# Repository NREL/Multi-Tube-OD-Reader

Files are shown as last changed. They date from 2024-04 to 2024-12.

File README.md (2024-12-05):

# Multi-Tube-OD-Reader
### Author: Skyler Hebdon, PhD
### Overview
Our **Multi-Tube-OD-Reader** device is based on the TubeOD reader [published here](https://doi.org/10.3389/fmicb.2021.790576), but with a housing to maximize throughput.

This repository contains the schematics for 3D printing an enclosure, a parts list for constructing, and the code for controlling the 16-tube, in-line optical density monitoring device. This device and software are particularly useful for researchers studying microbes that grow well in Hungate tubes, but are not amenable to growth in microplate readers.

- [Features](#features)
- [Limitations](#limitations)
- [Tutorial](#interacting-with-the-instrument)
- [Installation](#installation)
- [For Developers](#app-structure-mostly-for-developers--troubleshooting)
- [License](#license)

### Features
- **Real-time Monitoring:** View the OD measurements of multiple cultures in real time. Supports multiple, simultaneous, independent experiments.
- **User-Friendly Interface:** Easy-to-use, browser-based GUI for data collection and managing hardware. Install the software, connect the USB cable, connect the power cable and it's ready to go.
- **Calibration-ready:** Supports custom calibration tables to scale optical density readings to your favorite standard instrument. Raw data are always saved. Interpreted data can be saved as an xlsx file and include calibration tables. 
- **Multi-User Safe:** Experiments are spun-off as independent processes that continue even if the app is closed. Unique file naming is enforced to ensure that previous data cannot be overwritten. 
- **High throughput:** Connect as many Multi-Tube-OD-Readers as your incubator can hold. USB splitters and GUI allow identification and control of parallel independent instruments.

[Back to top](#overview)
### Limitations
- The hardware was designed for observing optical densities of *Clostridium thermocellum* growing in glass Hungate tubes. The optical properties of the glassware, medium and organism can interfere with the sensitivity of the instrument, especially at lower optical densities.
- The code works for us. It is not extensively tested and may require some modification on your machine.

[Back to top](#overview)
### Interacting with the Instrument
#### Nomenclature
- A *Device* is the whole unit with 16 Ports in it.
- A *Port* holds and measures one tube. Each Port can operate independently.
- An *Experiment* is a set of Ports & Devices taking measurements. Experiments run in the background indefinitely, until they are shut off in the app by the user or until the computer restarts.
#### Instrument Setup
Initial installation instructions are provided below. For routine use...

**Start the Shiny App** (if necessary) 
```
#from the Multi-Tube-OD-Reader directory
python -m shiny run --reload --launch-browser my_app/app.py 
```
This should open your default web browser and show the user interface.
### User Interface
#### Home: 
- View & interact with ongoing Experiments.
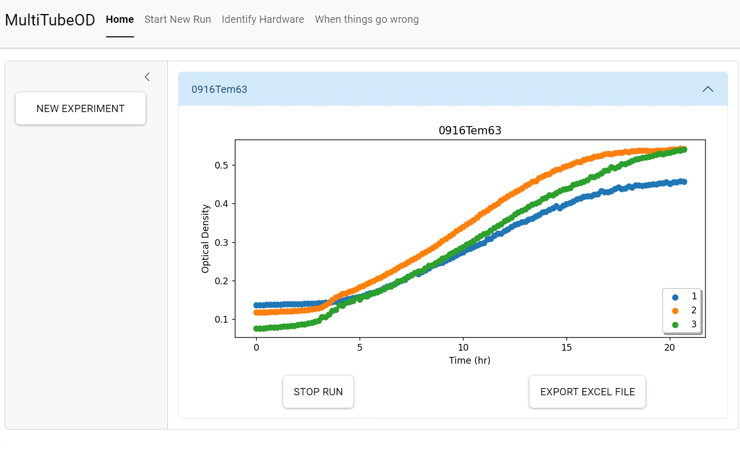
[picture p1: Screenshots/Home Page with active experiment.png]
Image of Home Page with growth curve data showing for an active experiment


- Safeguards protect from accidentally stopping the run.
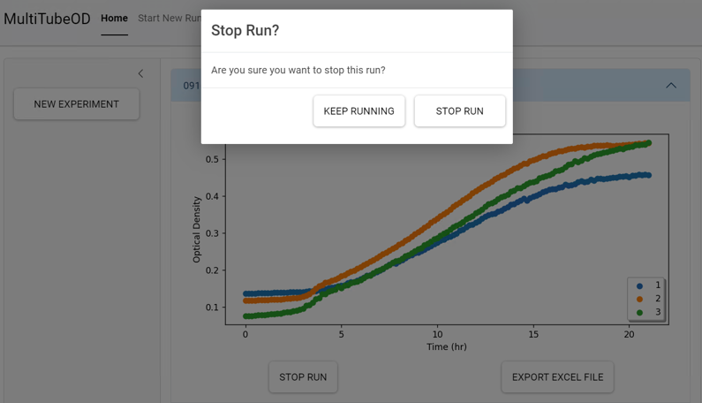
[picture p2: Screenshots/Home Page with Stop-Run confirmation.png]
Image of Home Page with a popup confirming user's intention to shut down the run


#### Start New Run:
- Step 1: Experiment name and measurement interval
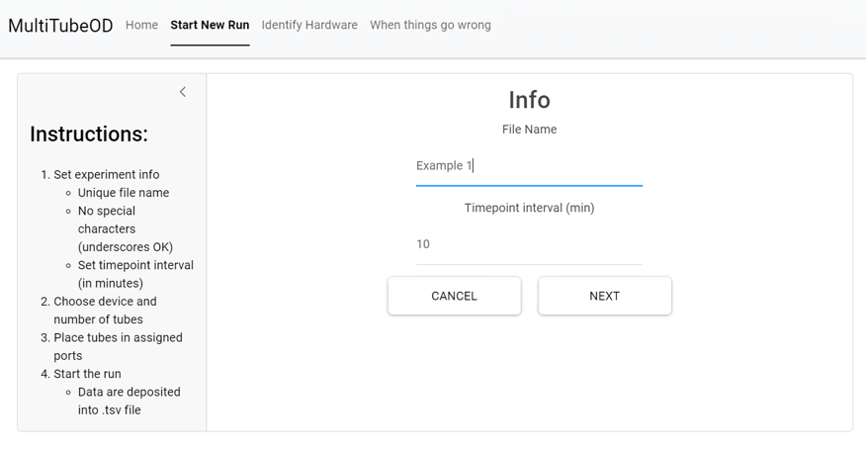
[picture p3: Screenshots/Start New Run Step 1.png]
Image of Start New Run page accepting experiment name and time interval inputs


- Safeguards to protect from overwriting previous data files.
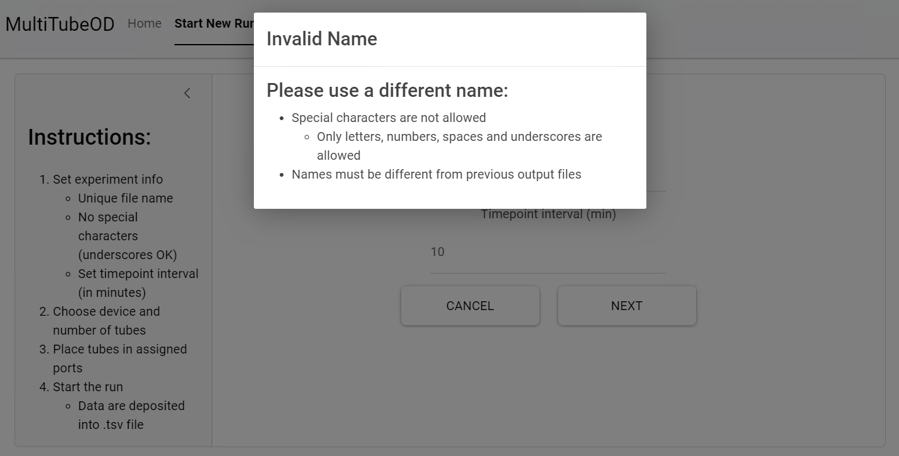
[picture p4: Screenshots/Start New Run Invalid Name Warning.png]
Image of Start New Run page warning user that the file name already exists


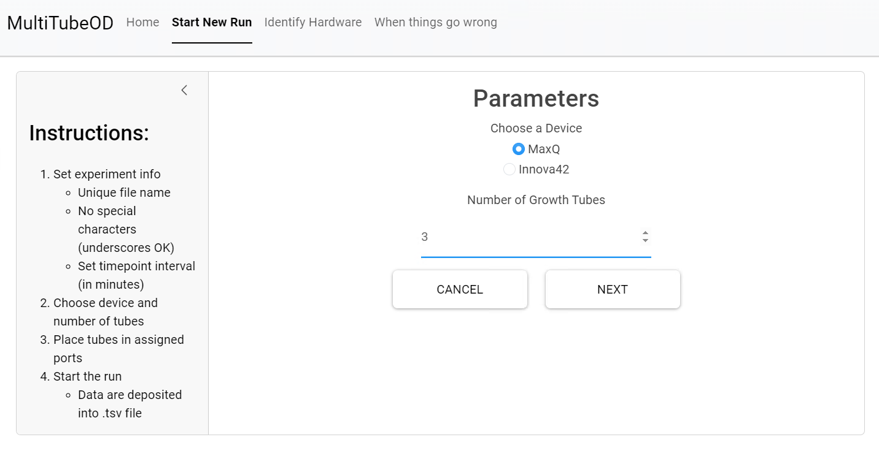
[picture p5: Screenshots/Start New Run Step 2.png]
Image of Start New Run page showing options for attached devices and number of available ports
- Step 2: Select device and number of Ports. We named our devices based on the incubators they live in. 

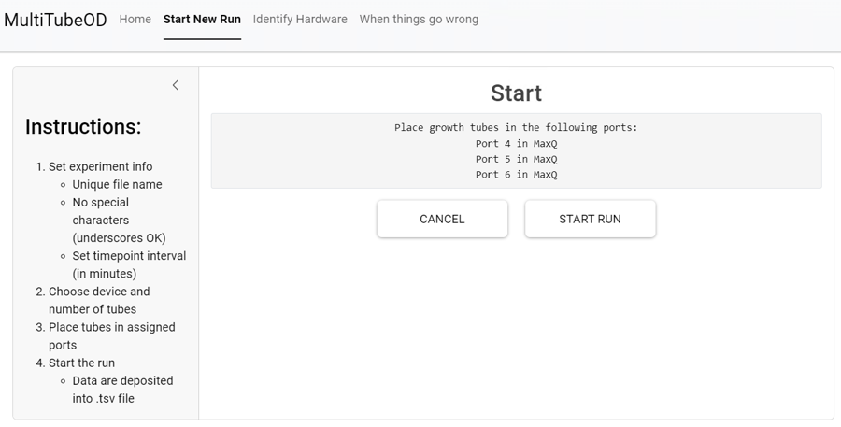
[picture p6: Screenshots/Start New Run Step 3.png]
Image of Start New Run page showing instructions on where to place culture tubes
- Step 3: Place growth tubes. Ports are automatically assigned based on availability. 

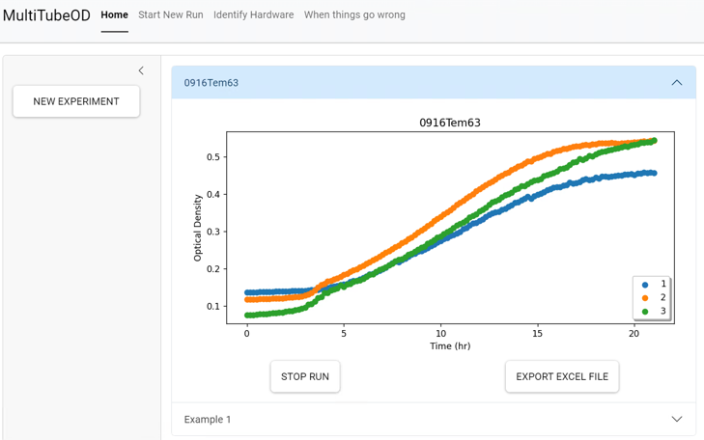
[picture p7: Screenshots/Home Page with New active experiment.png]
Image of Home Page with a new experiment added
- Complete: The User is automatically redirected to the Home Page with the New Experiment added to the list of Active Experiments. 

#### Configure Hardware:
- Identify and Rename devices. The Blink button makes the indicator LED blink on the device. 
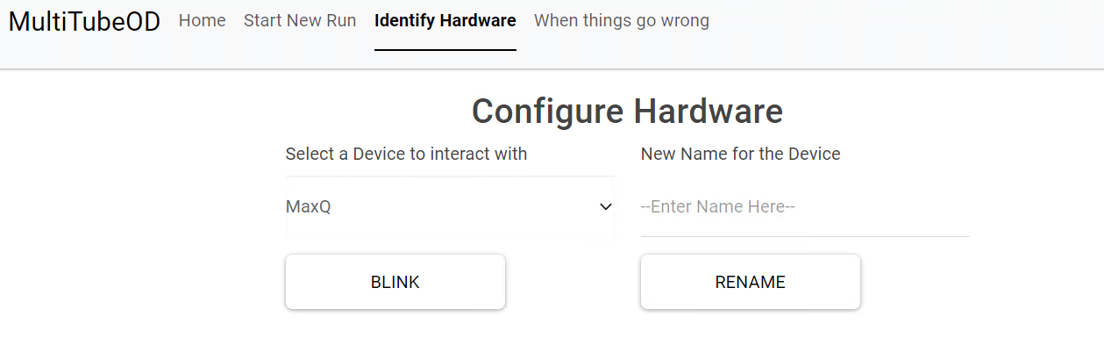
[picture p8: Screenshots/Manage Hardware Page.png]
Image of Configure Hardware page showing options to select a device, make it blink and rename it


#### Calibration: 
Performed mostly offline, no tab for this function
- Prepare reference tubes to several known optical densities. 
- Measure each reference level using each port the Multi-Tube-OD-Reader
- Transform raw Voltage data to log<sub>10</sub>( Voltage ) 
- Fit a line with y = Known data and x = log<sub>10</sub>( Voltage )
- Update the slope & intercept for each port and other relevant data into the `Calibration.tsv` found in the `my_app` directory.

[Back to top](#overview)
### Installation 
#### Hardware
The hardware requires two connections:
1. A USB cable for data transfer to the computer.
	- USB splitters can be used to branch one USB cable from the computer to multiple Devices. This can help reduce the number of cables passing through the incubator.
2. A power supply cable providing up to about 0.5 amps of 5V DC electrical power.
#### Software
The app requires a Python environment and a U3-compatible driver from [LabJack.com](https://support.labjack.com/docs/labjackpython-for-ud-exodriver-u12-windows-mac-lin).
- For Windows: the UD Driver
- Linux macOS: the Exodriver 

All other required packages are either listed in the `requirements.txt` file or provided in this repository. The following instructions are a typical way to install all of them.

**Copy this Repository to the Computer connected to the Device:** 
 ```
 git clone https://github.com/NREL/Multi-Tube-OD-Reader.git
 ```

**Navigate to the Project Directory:**
```
cd Multi-Tube-OD-Reader
```

**Create a Virtual Environment (Optional):**
Windows users may have different strategies for activating a python virtual environment in WSL vs cmd vs PowerShell. PowerShell users see [this answer](https://stackoverflow.com/a/59815372) 
```
python -m venv MTOD
source MTOD/bin/activate 
```

**Install Dependencies:**
```
pip install -r my_app/requirements.txt
```

**Start the Shiny App**
```
#from Multi-Tube-OD-Reader directory
python -m shiny run --reload --launch-browser my_app/app.py 
```

[Back to top](#overview)
### App Structure (mostly for developers & troubleshooting)
The app was written in Python using modules in a three-tier architecture:
1. *A minimal* `timecourse.py` *script*. This script, and the receives a `.csv` file with instructions in the header that describe the measurement parameters. This script controls the Multi-Tube-OD-Reader device throughout the duration of an experiment and feeds raw data into the `.csv` file. This script was designed to be lightweight so multiple parallel-independent instances can run simultaneously without crashing the computer.
2. *Three custom Python classes* `Device`, `Port`, *and* `Experiment` *mirroring their physical counterparts.* Objects of these classes convey data between the GUI, a `config.dat` file, and the instrument. The `config.dat` file stores the status of the instrument and active experiments in case the app closes. Only the `Device` class (and `timecourse.py` script) interact directly with the instrument.
3. *Modules comprising the GUI. Written in Shiny for Python.* This runs a server on localhost. Advanced users may be able to serve the app to remote clients to monitor the data. We simply use remote login to the laptop running the app. The modules on this tier serve several functions:
	1. Convert user parameters to inputs to `timecourse.py` 
	2. Store instrument and app state in `config.dat`
	3. Calculate valid options for user input
	4. Reject or correct invalid user input

[Back to top](#overview)
### License
The hardware and software were built from open source resources. The material in this repository were developed at the National Renewable Energy Laboratory, with the code being reported under SWR-24-126. The materials in this repository are subject to the BSD-3-Clause License. 

**No Guarantees:**
- **Accuracy:** We make no representations or warranties about the accuracy, reliability, completeness, or timeliness of the content. The instructions and information provided may contain errors or inaccuracies.
- **Functionality:** We do not guarantee that the hardware or software will function correctly or meet your needs. There may be unforeseen issues or incompatibilities that arise during implementation.
- **Support:** There is no obligation to provide support, maintenance, or updates for the materials provided in this repository.

[Back to top](#overview)

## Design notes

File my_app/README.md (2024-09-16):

# Multi-Tube-OD-Reader
### Overview
Our **Multi-Tube-OD-Reader** device is based on the TubeOD reader [published here](https://doi.org/10.3389/fmicb.2021.790576), but with a housing to maximize throughput.

This repository contains the schematics for 3D printing an enclosure, a parts list for constructing, and the code for controlling the 16-tube, in-line optical density monitoring device. This device and software are particularly useful for researchers studying microbes that grow well in Hungate tubes, but are not amenable to growth in microplate readers.
### Features
- **Real-time Monitoring:** View the OD measurements of multiple cultures in real time. Supports multiple, simultaneous, independent experiments.
- **User-Friendly Interface:** Easy-to-use, browser-based GUI for data collection and managing hardware. Install the software, connect the USB cable, connect the power cable and it's ready to go.
- **Calibration-ready:** Supports custom calibration tables to scale optical density readings to your favorite standard instrument. Raw data are always saved. Interpreted data can be saved as an xlsx file and include calibration tables. 
- **Multi-User Safe:** Experiments are spun-off as independent processes that continue even if the app is closed. Unique file naming is enforced to ensure that previous data cannot be overwritten. 
- **High throughput:** Connect as many Multi-Tube-OD-Readers as your incubator can hold. USB splitters and GUI allow identification and control of parallel independent instruments.
### Limitations
- The hardware was designed for observing optical densities of *Clostridium thermocellum* growing in glass Hungate tubes. The optical properties of the glassware, medium and organism can interfere with the sensitivity of the instrument, especially at lower optical densities.
- The code works for us. It is not extensively tested and may require some modification on your machine.
### Interacting with the Instrument and GUI
##### Nomenclature
- A *Device* is the whole unit with 16 Ports in it.
- A *Port* holds and measures one tube. Each Port can operate independently.
- An *Experiment* is a set of Ports & Devices taking measurements. Experiments run in the background indefinitely, until they are shut off in the app by the user or until the computer restarts.
##### Instrument Setup
Initial installation instructions are provided below. For routine use...
**Start the Shiny App** (if necessary) 
```
#from the Multi-Tube-OD-Reader directory
python -m shiny run --reload --launch-browser my_app/app.py 
```
This should open your default web browser and show the user interface.
##### User Interface
**Home:** View ongoing Experiments.
- Minimize or expand experiments to view data and reveal options to export interpreted data or terminate the experiment. 
**Start New Run:** Define the following parameters for starting a new Experiment.
- Experiment Name
- Interval between measurements 
- Name of Device to use
- Number of Ports to use
**Configure Hardware:** Manage connected devices.
- Select Device by name
- Activate LED "Blink" mode on hardware
- Rename Device with a meaningful identifier

**Calibration** (performed mostly offline, no tab for this function)
- Prepare reference tubes to several known optical densities. 
- Measure each reference level using each port the Multi-Tube-OD-Reader
- Transform raw Voltage data to log$_{10}$( Voltage ) 
- Fit a line with y = Known data and x = log$_{10}$( Voltage )
- Update the slope & intercept for each port and other relevant data into the `Calibration.tsv` found in the `my_app` directory.
### Installation 
##### Hardware
The hardware requires two connections:
1. A USB cable for data transfer to the computer.
	- USB splitters can be used to branch one USB cable from the computer to multiple Devices. This can help reduce the number of cables passing through the incubator.
2. A power supply cable providing up to about 0.5 amps of 5V DC electrical power.
##### Software
The app requires a U3-compatible driver from [LabJack.com](https://support.labjack.com/docs/labjackpython-for-ud-exodriver-u12-windows-mac-lin).
- For Windows: the UD Driver
- Linux macOS: the Exodriver 

All other required packages are either listed in the `requirements.txt` file or provided in this repository. The following instructions are a typical way to install all of them.

**Copy this Repository to the Computer connected to the Device:** 
 ```
 git clone https://github.com/NREL/Multi-Tube-OD-Reader.git
 ```

**Navigate to the Project Directory:**
```
cd Multi-Tube-OD-Reader
```

**Create a Virtual Environment (Optional):**
Windows users may have different strategies for activating a python virtual environment in WSL vs cmd vs PowerShell. PowerShell users see [this answer](https://stackoverflow.com/a/59815372) 
```
python -m venv MTOD
source MTOD/bin/activate 
```

**Install Dependencies:**
```
pip install -r my_app/requirements.txt
```

**Start the Shiny App**
```
#from Multi-Tube-OD-Reader directory
python -m shiny run --reload --launch-browser my_app/app.py 
```
### App Structure (mostly for developers & troubleshooting)

The app was written in Python using modules in a three-tier architecture:
1. *A minimal* `timecourse.py` *script*. This script, and the receives a `.csv` file with instructions in the header that describe the measurement parameters. This script controls the Multi-Tube-OD-Reader device throughout the duration of an experiment and feeds raw data into the `.csv` file. This script was designed to be lightweight so multiple parallel-independent instances can run simultaneously without crashing the computer.
2. *Three custom Python classes* `Device`, `Port`, *and* `Experiment` *mirroring their physical counterparts.* Objects of these classes convey data between the GUI, a `config.dat` file, and the instrument. The `config.dat` file stores the status of the instrument and active experiments in case the app closes. Only the `Device` class (and `timecourse.py` script) interact directly with the instrument.
3. *Modules comprising the GUI. Written in Shiny for Python.* This runs a server on localhost. Advanced users may be able to serve the app to remote clients to monitor the data. We simply use remote login to the laptop running the app. The modules on this tier serve several functions:
	1. Convert user parameters to inputs to `timecourse.py` 
	2. Store instrument and app state in `config.dat`
	3. Calculate valid options for user input
	4. Reject or correct invalid user input
### License
The hardware and software were built from open source resources. The material in this repository were developed at the National Renewable Energy Laboratory under the Laboratory-Directed Research & Development program. The materials in this repository are subject to  ##########License##############

**No Guarantees:**
- **Accuracy:** We make no representations or warranties about the accuracy, reliability, completeness, or timeliness of the content. The instructions and information provided may contain errors or inaccuracies.
- **Functionality:** We do not guarantee that the hardware or software will function correctly or meet your needs. There may be unforeseen issues or incompatibilities that arise during implementation.
- **Support:** There is no obligation to provide support, maintenance, or updates for the materials provided in this repository.

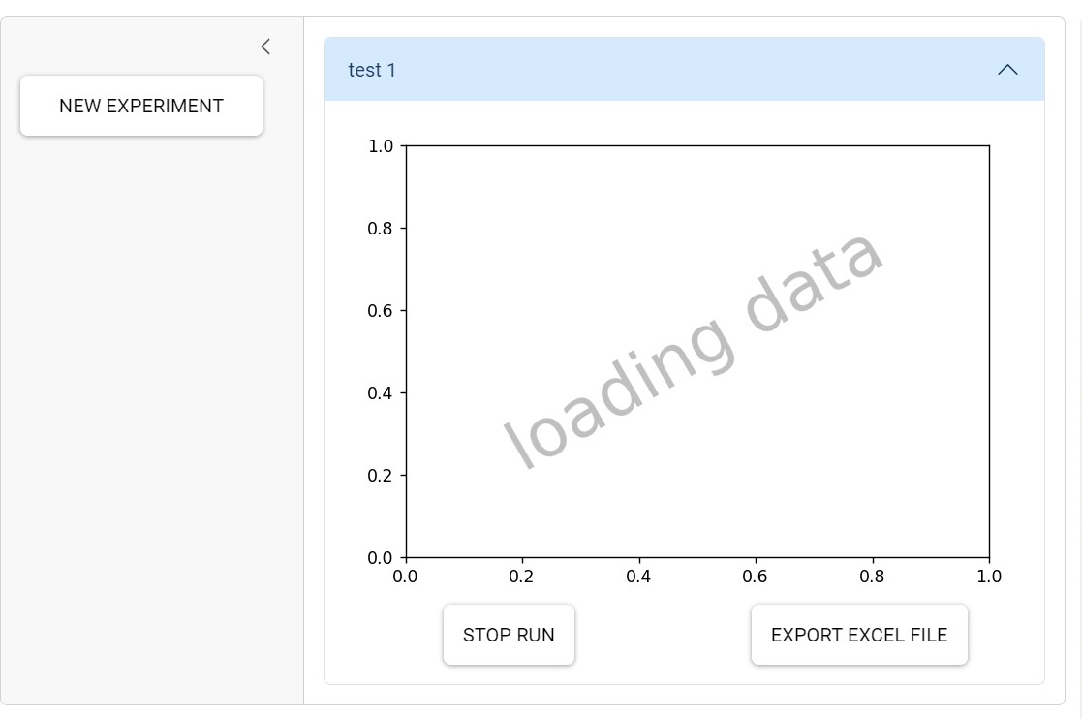
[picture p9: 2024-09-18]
Screenshots/Data loading screen.jpg

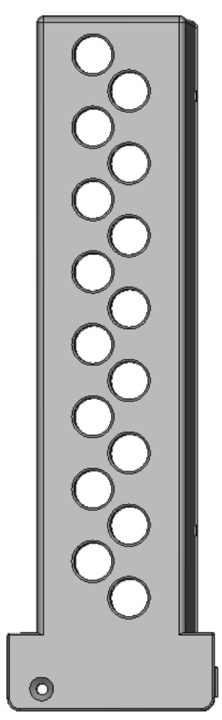
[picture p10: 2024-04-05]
my_app/cover.png

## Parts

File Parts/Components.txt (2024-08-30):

Part	Supplier	MFR #	Supplier #	Per tube	per unit
LED	Digikey		C566C-AFF-CU0W0252CT-ND	1	16
LED Driver IC	Digikey		CL220N5-G-ND	1	16
sensor	Amazon	TEMT6000	https://www.amazon.com/Coliao-TEMT6000-Professional-Intensity-Visible/dp/B0BZTZHRZS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	1	16
3-pin receptacle	Newark 	22-01-3037	38C9145	1	16
3-pin 90 degree header	Digikey		WM4301-ND	1	16
Contact sockets	Newark 	08-50-0032	62X0650	3	48
2-conductor cable - 22 gauge	Digikey	30-01253	T1412-5-ND		
3-conductor cable - 22 gauge	Digikey	8450 0101000	BEL1308-50-ND		
10-pin receptacle (locking)	Digikey	wm8037-nd	901420010		
10-pin header (locking)	Digikey	wm8325-nd	901301110		
Crimps for 10-pin header			WM2510-ND		
LabJack	LabJack				1
USB cable	Digikey		5214-USBAB2ML-ND		1
USB header	Newark 	USBR-B-S-S-O-TH	14R4574		1
2.1 mm x 5.5 mm Barrel jack to 18 gauge bare wire	Digikey	10-03610	839-10-03610-ND		1
"power supply, 2.5mm x 5.5mm x 9.5 mm"	Digikey	16-00015	839-1660-ND		1
LM317	Digikey		296-13869-5-ND		1
Solidstate relay	Digikey	AM37	3008-AB37-ND		1
screws (pack of 50)	Digikey		HM1442-ND		36
long screws (pack of 100)	Digikey	1591TS100			4

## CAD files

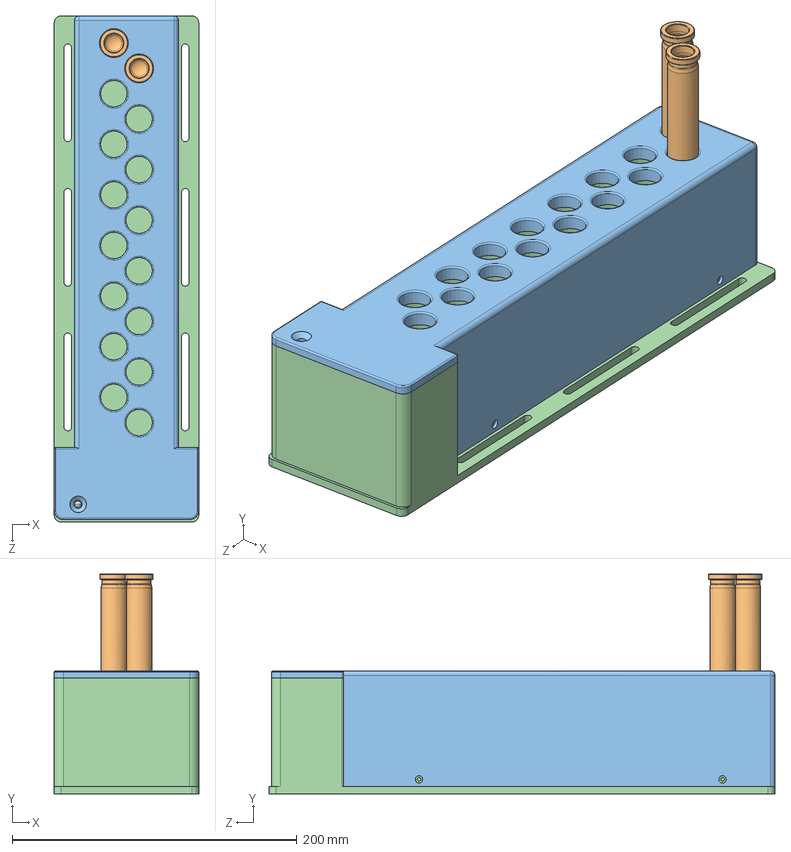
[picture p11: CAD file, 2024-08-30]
Parts/3181-03-00.SLDASM
101.6 x 154.4 x 355.6 mm
u3_pcba-20201207

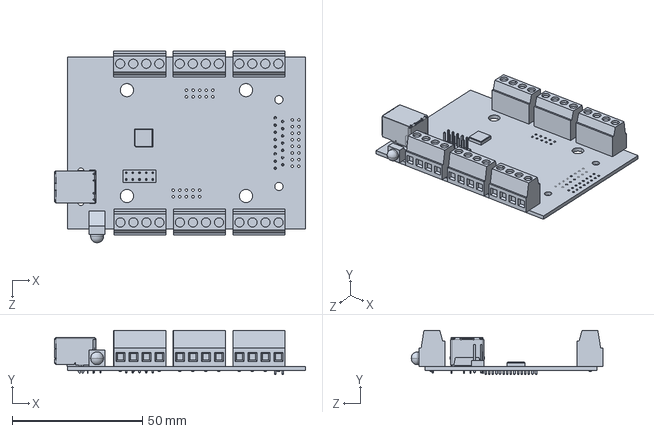
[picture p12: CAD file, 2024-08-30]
Parts/u3_pcba-20201207.SLDPRT
96.4 x 17.0 x 73.6 mm

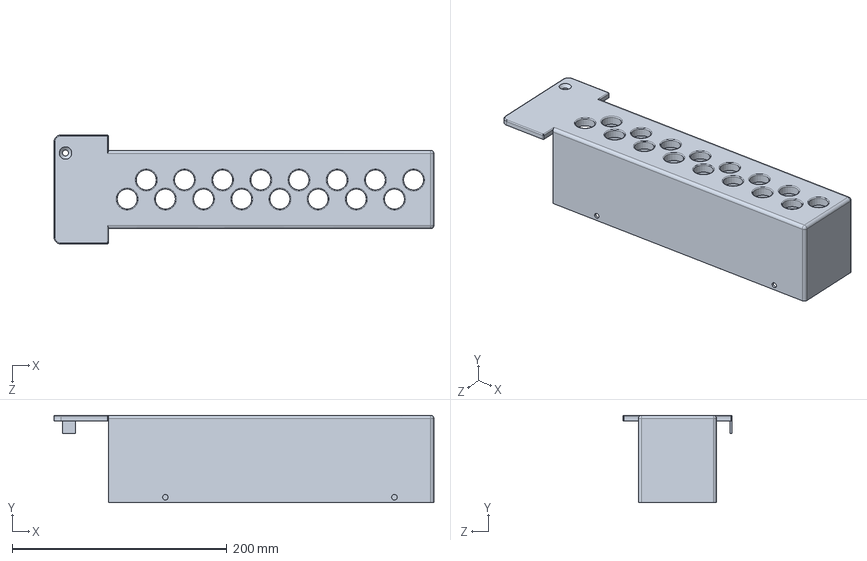
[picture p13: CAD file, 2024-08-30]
Parts/3181-03-01.SLDPRT
353.9 x 81.4 x 101.6 mm

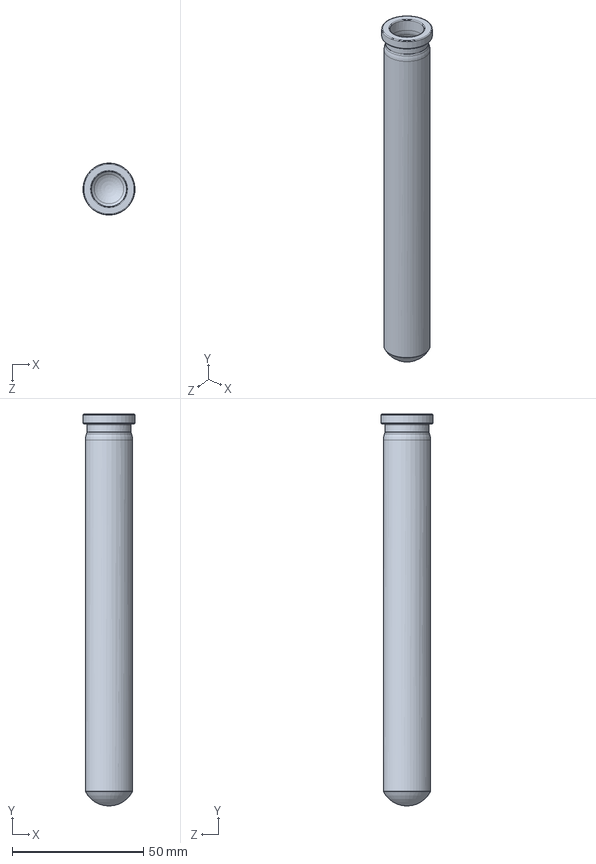
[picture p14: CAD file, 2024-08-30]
Parts/3181-00-01.SLDPRT
19.8 x 149.3 x 19.8 mm

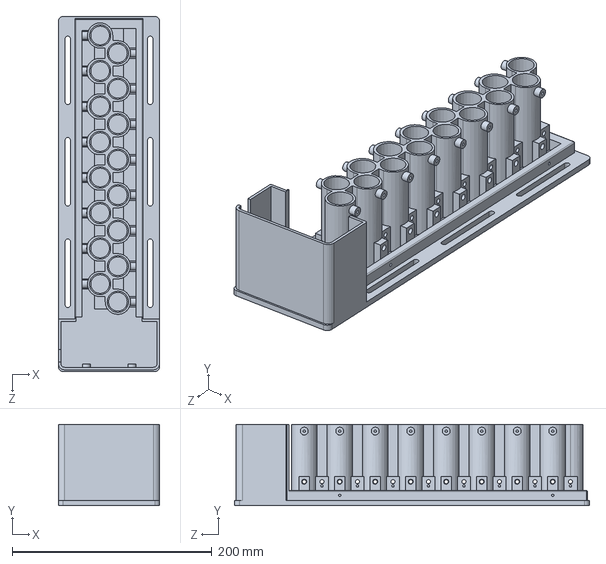
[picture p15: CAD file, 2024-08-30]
Parts/3181-03-02.SLDPRT
101.6 x 81.3 x 355.6 mm

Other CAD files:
Parts/3181-03-00.SLDDRW
Parts/3181-03-01.SLDDRW
Parts/3181-03-02.SLDDRW

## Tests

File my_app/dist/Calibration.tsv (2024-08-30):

DeviceID | Port | Slope | Intercept | R^2 | Date
320025052 | 1 | -0.49810642 | 0.287882165 | 0.997644899 | 7/29/2024
320025052 | 2 | -0.490788072 | 0.288915886 | 0.998286524 | 7/29/2024
320025052 | 3 | -0.490815332 | 0.337320501 | 0.998269742 | 7/29/2024
320025052 | 4 | -0.480658977 | 0.359227182 | 0.998849789 | 7/29/2024
320025052 | 5 | -0.489034053 | 0.31131613 | 0.998755798 | 7/29/2024
320025052 | 6 | -0.485325195 | 0.33445871 | 0.998549341 | 7/29/2024
320025052 | 7 | -0.492118058 | 0.327207934 | 0.998784087 | 7/29/2024
320025052 | 8 | -0.484903094 | 0.325601678 | 0.99828353 | 7/29/2024
320025052 | 9 | -0.495081668 | 0.301432224 | 0.998768022 | 7/29/2024
320025052 | 10 | -0.510185944 | 0.361506642 | 0.999956892 | 7/29/2024
320025052 | 11 | -0.498155733 | 0.303244371 | 0.998926699 | 7/29/2024
320025052 | 12 | -0.488435079 | 0.335390904 | 0.998651473 | 7/29/2024
320025052 | 13 | -0.485769313 | 0.350722889 | 0.998706716 | 7/29/2024
320025052 | 14 | -0.458743106 | 0.337553022 | 0.99877131 | 7/29/2024
320025052 | 15 | -0.489257424 | 0.353872979 | 0.99880573 | 7/29/2024
320025052 | 16 | -0.507890228 | 0.233422262 | 0.99757943 | 7/29/2024
320106158 | 1 | 1 | -0.001 | 1 | Fake
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

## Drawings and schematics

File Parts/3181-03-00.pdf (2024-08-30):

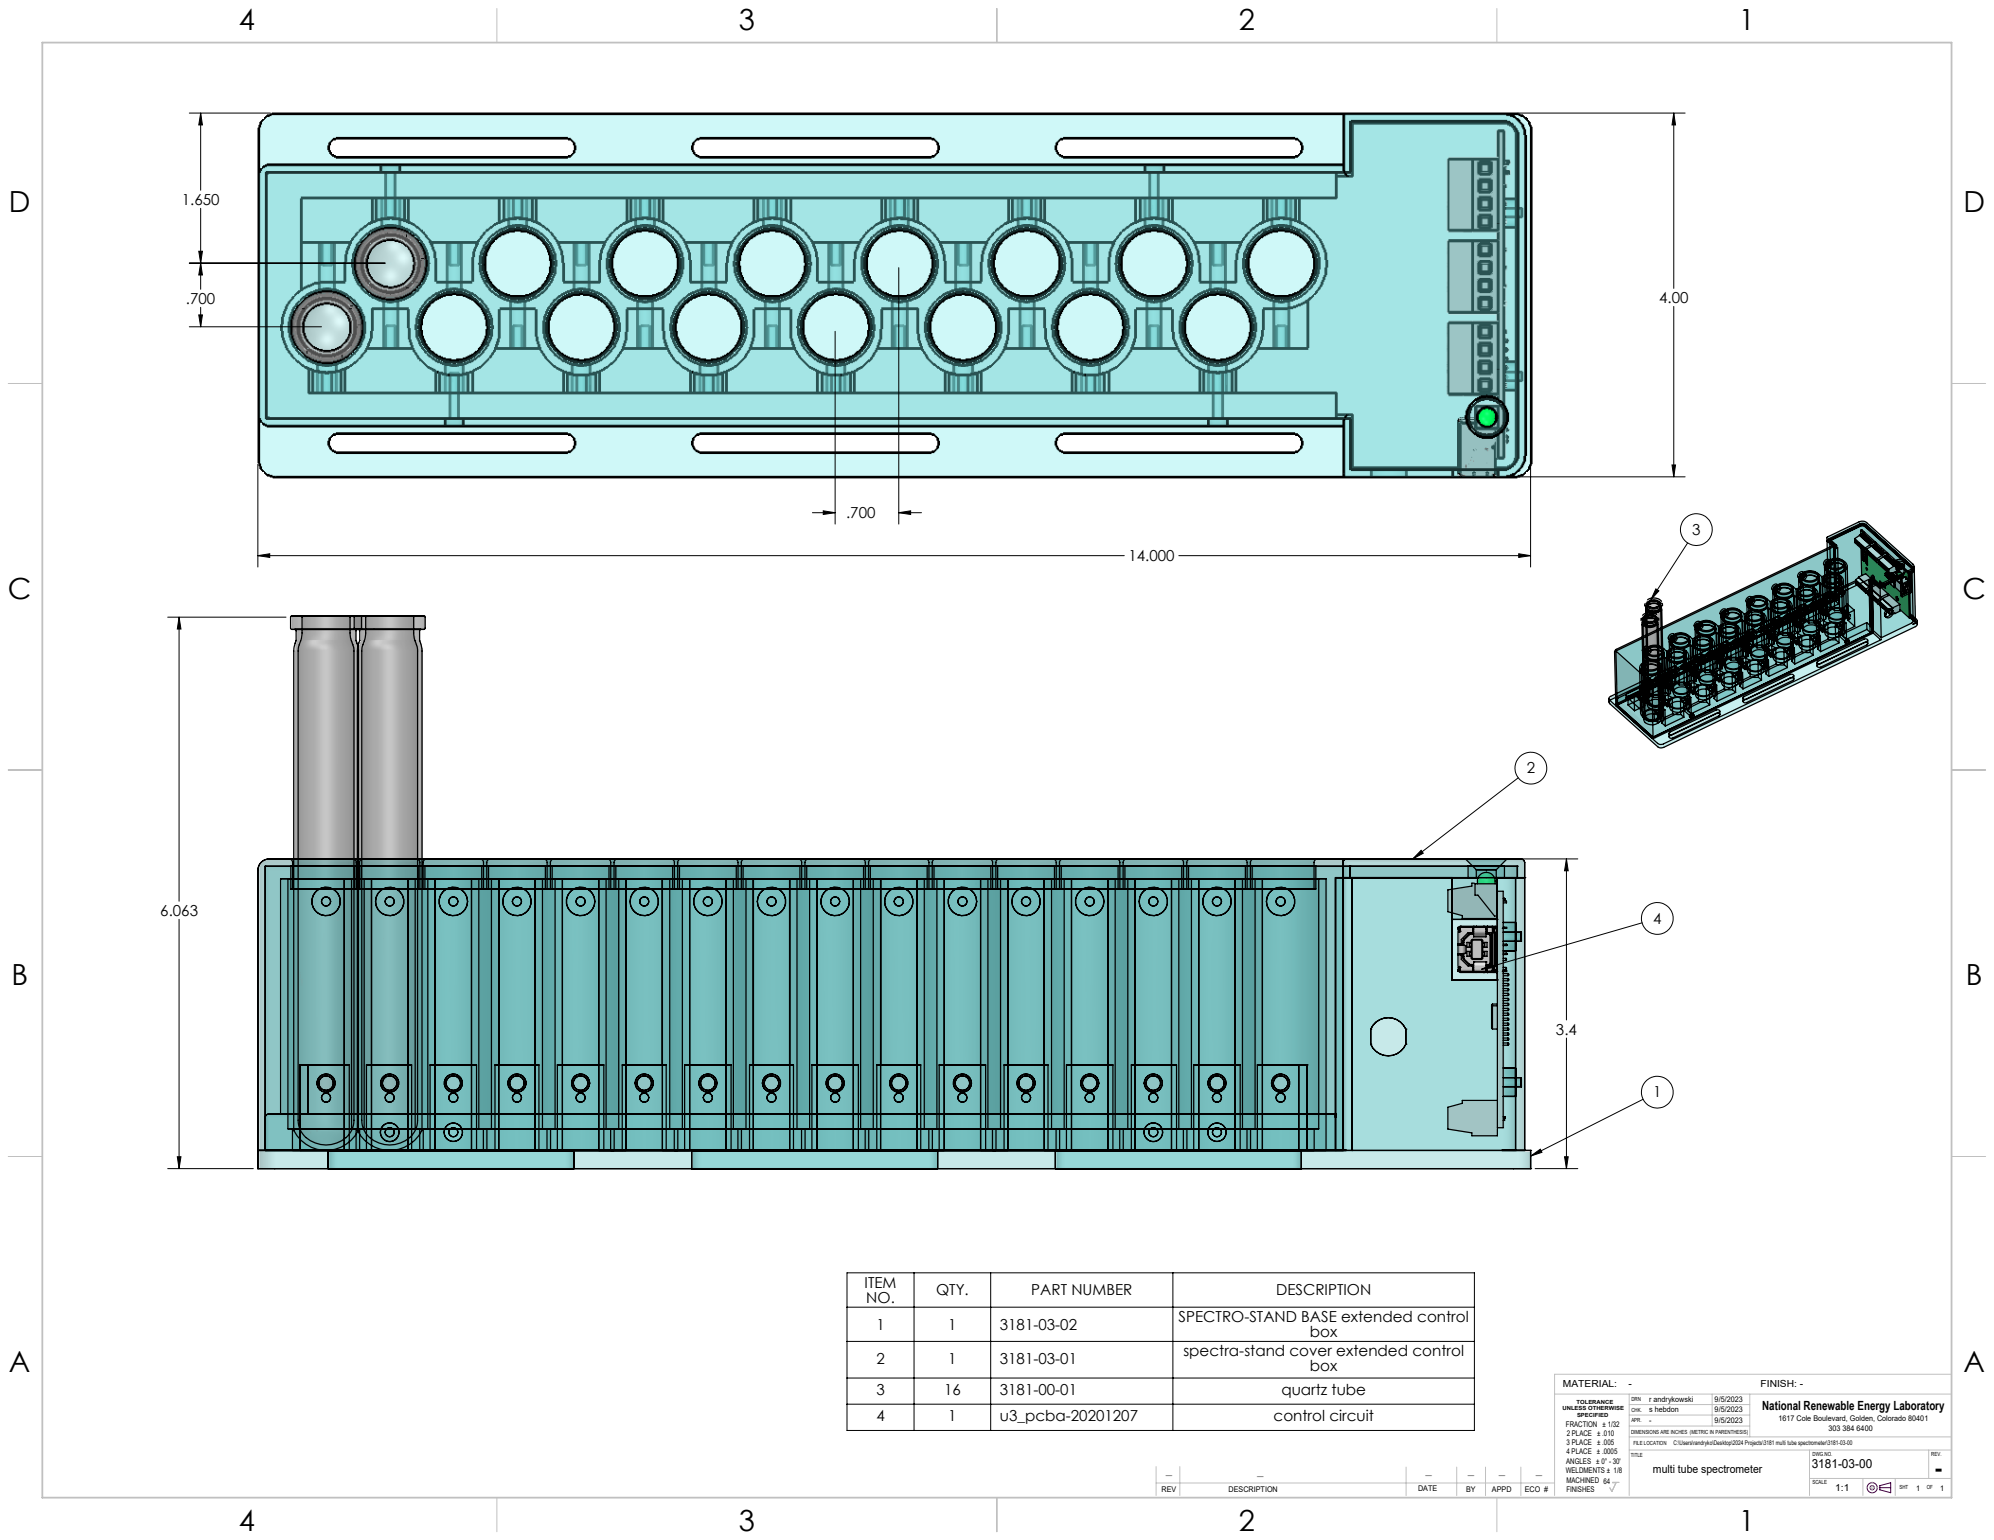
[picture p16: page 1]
FRACTION ± 1/32 2 PLACE ± .010 3 PLACE ± .005 4 PLACE ± .0005 ANGLES ± 0° - 30' WELDMENTS ± 1/8; UNLESS OTHERWISE; REV; DESCRIPTION; DATE; APPD; ECO #; MATERIAL: -; s hebdon

ITEM NO. | QTY. | PART NUMBER | DESCRIPTION
1 | 1 | 3181-03-02 | SPECTRO-STAND BASE extended control box
2 | 1 | 3181-03-01 | spectra-stand cover extended control box
3 | 16 | 3181-00-01 | quartz tube
4 | 1 | u3_pcba-20201207 | control circuit

FINISH: -
National Renewable Energy Laboratory
1617 Cole Boulevard, Golden, Colorado 80401

r andrykowski
DRN
CHK.
APR.
DIMENSIONS ARE INCHES (METRIC IN PARENTHESIS)
FILE LOCATION
TITLE
multi tube spectrometer

C:\Users\randryko\Desktop\2024 Projects\3181 multi tube spectrometer\3181-03-00

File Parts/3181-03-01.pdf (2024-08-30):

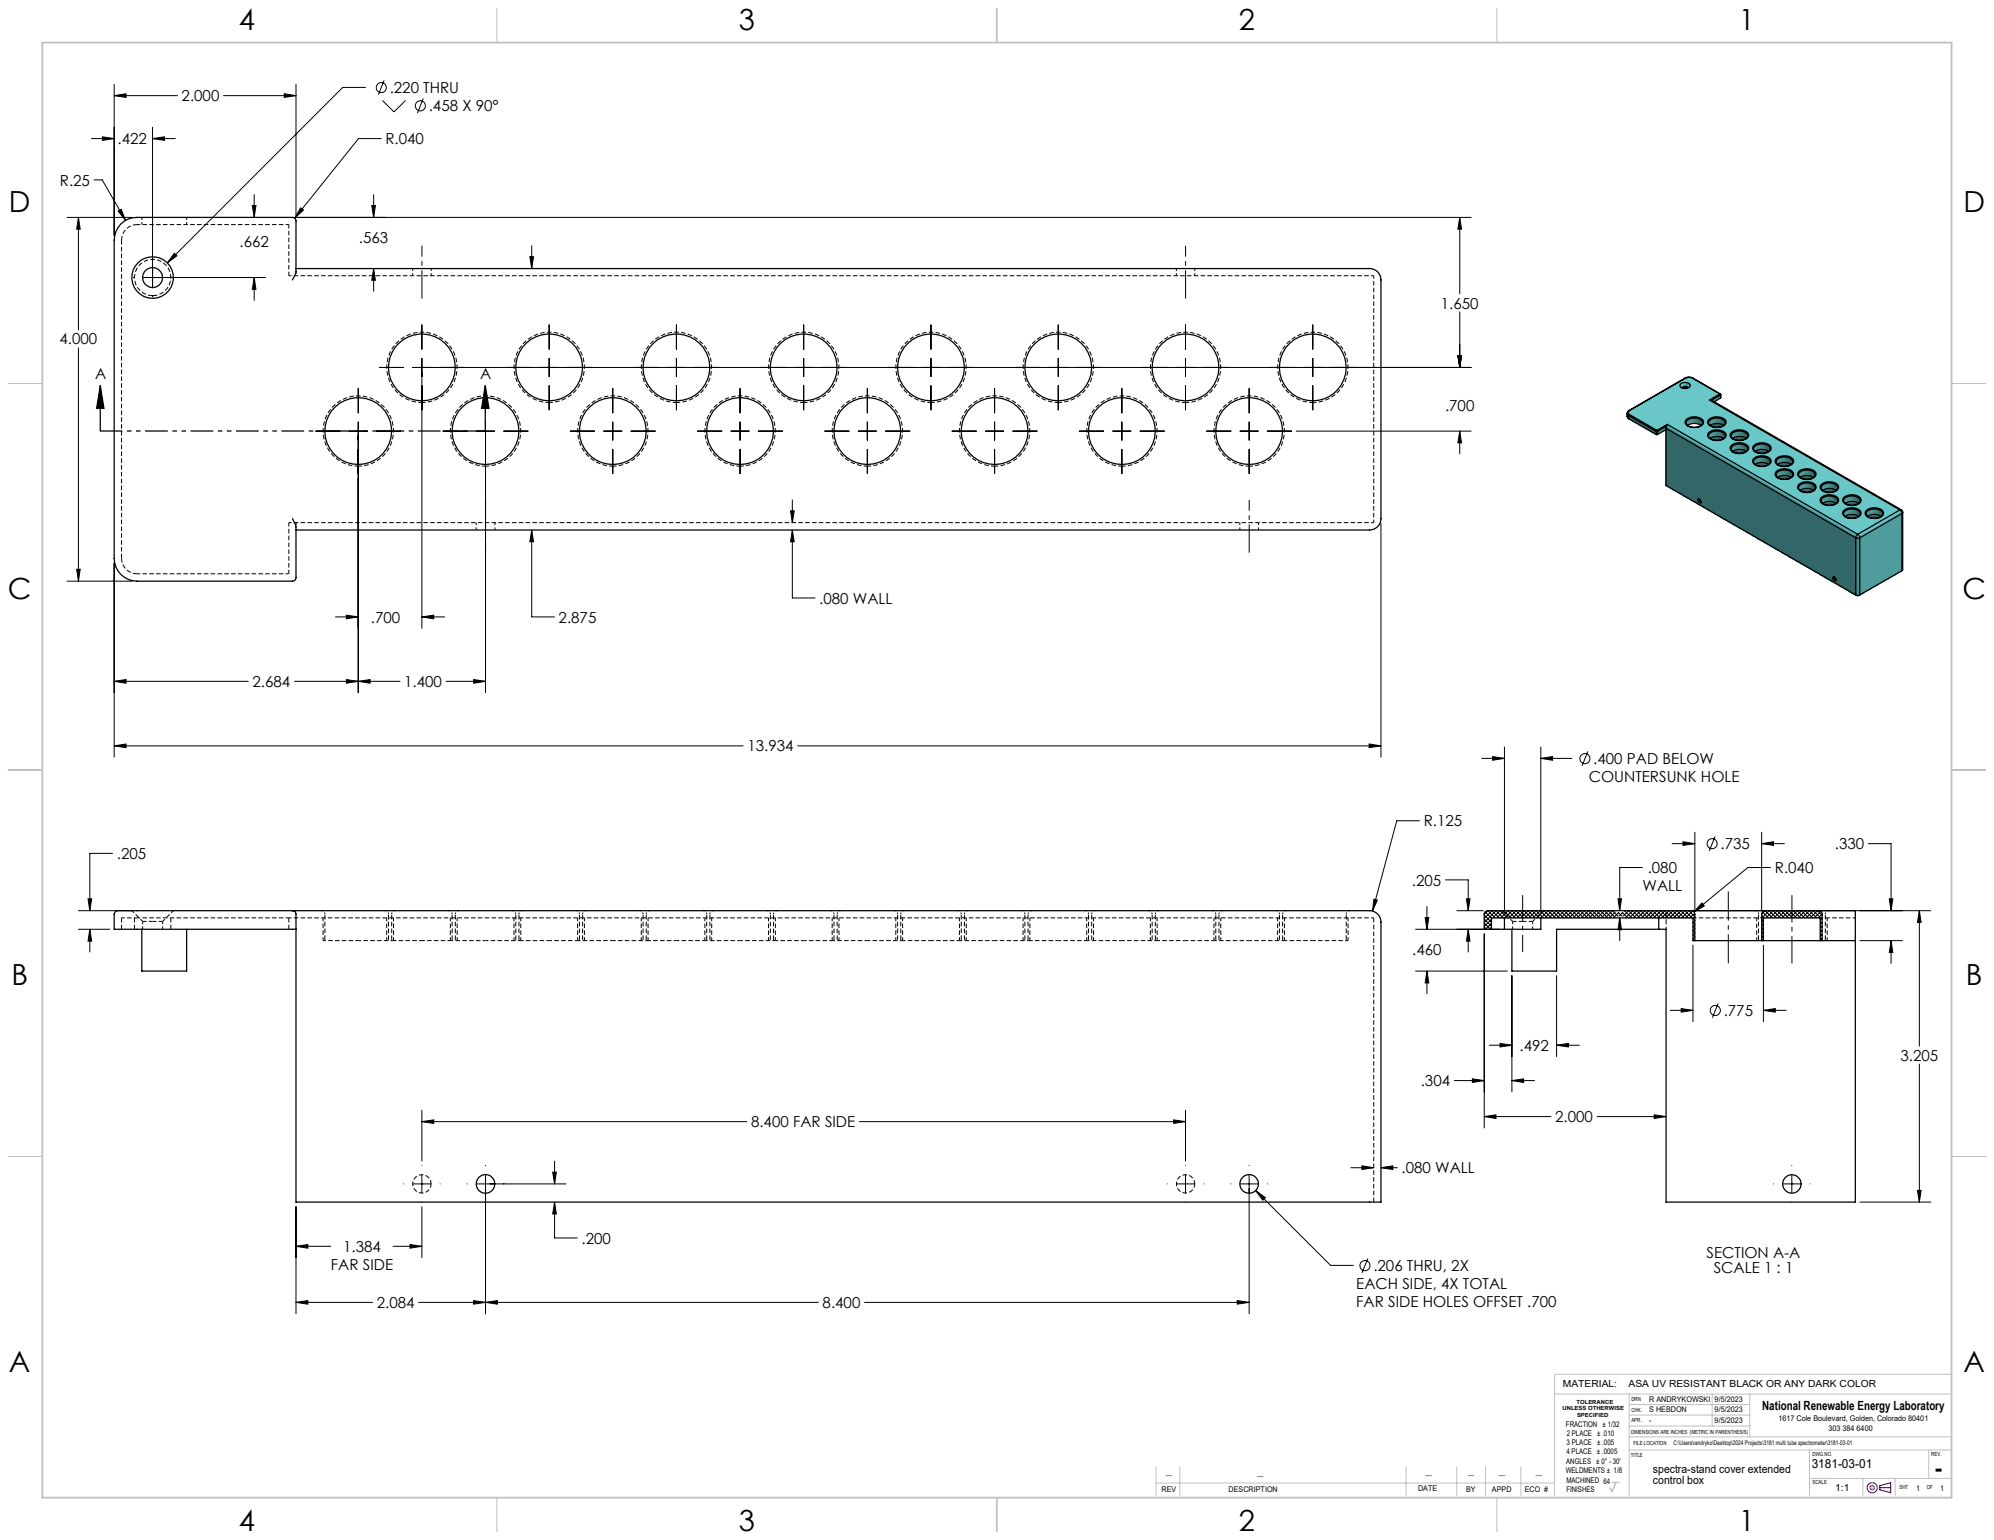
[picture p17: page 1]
.220 THRU .458 X 90°; .080 WALL; .400 PAD BELOW COUNTERSUNK HOLE; SECTION A-A SCALE 1 : 1; .200 1.384 FAR SIDE; 8.400 FAR SIDE; FRACTION ± 1/32 2 PLACE ± .010 3 PLACE ± .005 4 PLACE ± .0005 ANGLES ± 0° - 30' WELDMENTS ± 1/8; UNLESS OTHERWISE; REV; DESCRIPTION; DATE; APPD; ECO #; S HEBDON

.206 THRU, 2X
EACH SIDE, 4X TOTAL
FAR SIDE HOLES OFFSET .700

MATERIAL: ASA UV RESISTANT BLACK OR ANY DARK COLOR

R ANDRYKOWSKI
DRN
CHK.
APR.
DIMENSIONS ARE INCHES (METRIC IN PARENTHESIS)
FILE LOCATION
TITLE
spectra-stand cover extended
control box

National Renewable Energy Laboratory
1617 Cole Boulevard, Golden, Colorado 80401

C:\Users\randryko\Desktop\2024 Projects\3181 multi tube spectrometer\3181-03-01

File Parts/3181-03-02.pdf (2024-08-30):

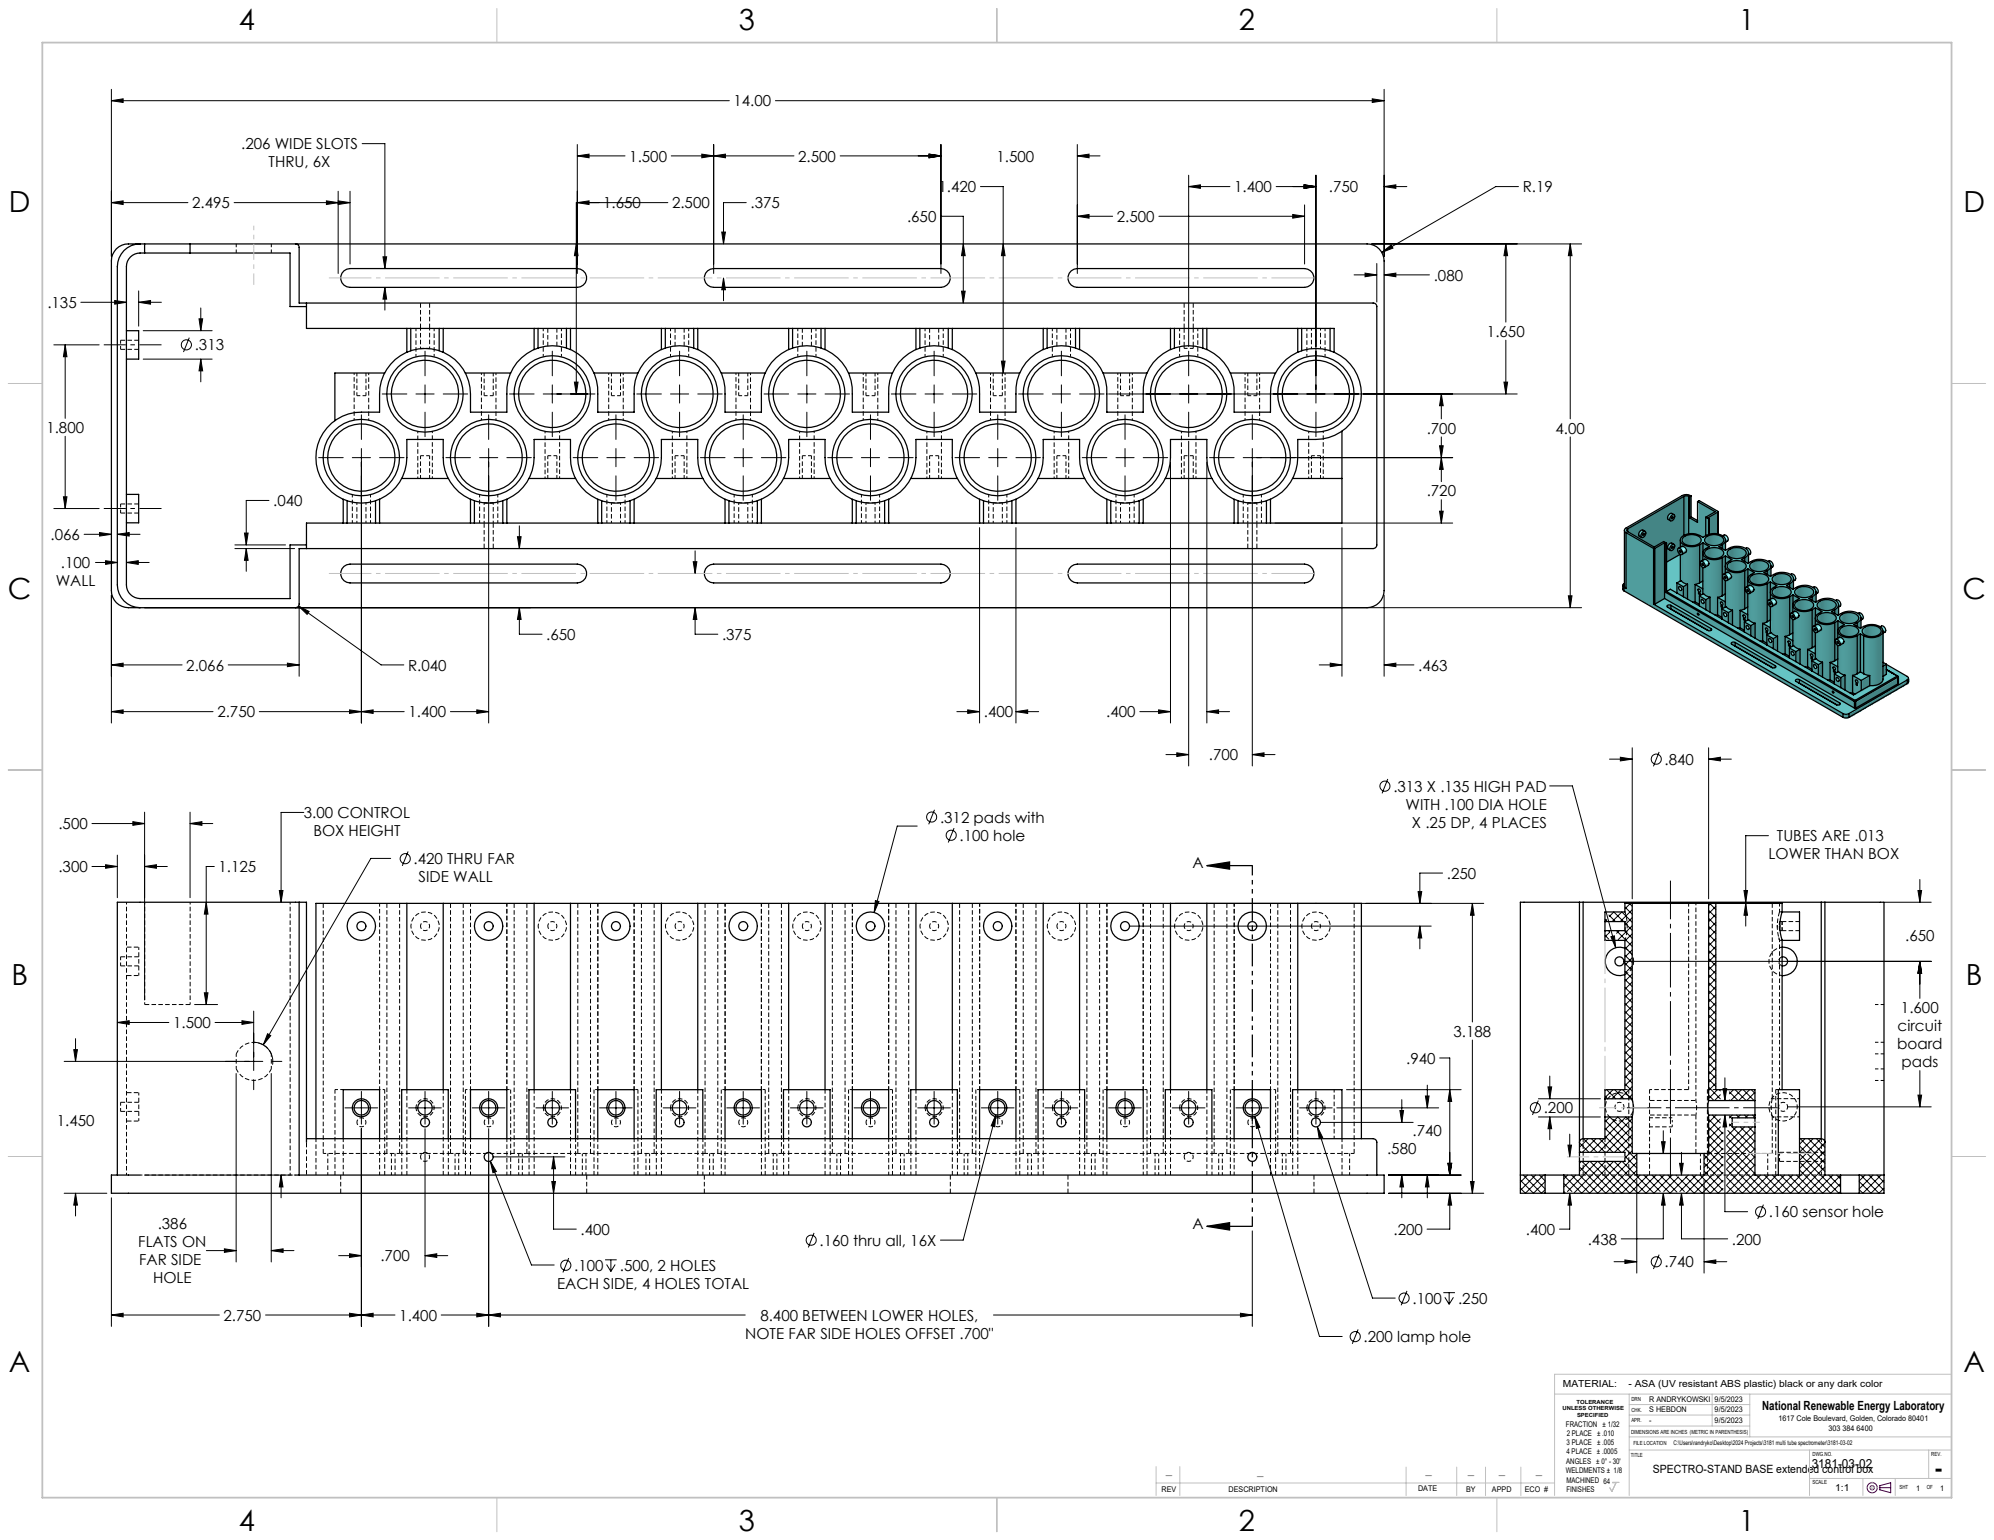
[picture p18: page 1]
.200 .160 thru all, 16X; .420 THRU FAR SIDE WALL; FLATS ON FAR SIDE; 3.00 CONTROL BOX HEIGHT; .200 lamp hole; .312 pads with .100 hole; .206 WIDE SLOTS THRU, 6X; .160 sensor hole; FRACTION ± 1/32 2 PLACE ± .010 3 PLACE ± .005 4 PLACE ± .0005 ANGLES ± 0° - 30' WELDMENTS ± 1/8; UNLESS OTHERWISE; REV; DESCRIPTION; DATE; APPD; ECO #; S HEBDON

.313 X .135 HIGH PAD
WITH .100 DIA HOLE
X .25 DP, 4 PLACES

TUBES ARE .013
LOWER THAN BOX

.100 .500, 2 HOLES
EACH SIDE, 4 HOLES TOTAL

8.400 BETWEEN LOWER HOLES,
NOTE FAR SIDE HOLES OFFSET .700"

MATERIAL: - ASA (UV resistant ABS plastic) black or any dark color

R ANDRYKOWSKI
DRN
CHK.
APR.
DIMENSIONS ARE INCHES (METRIC IN PARENTHESIS)
FILE LOCATION
TITLE
SPECTRO-STAND BASE extended control box

National Renewable Energy Laboratory
1617 Cole Boulevard, Golden, Colorado 80401

C:\Users\randryko\Desktop\2024 Projects\3181 multi tube spectrometer\3181-03-02

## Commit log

2023-12-12 Create Book1 (version 1).xlsx
    [Book1 (version 1).xlsx]
2024-01-18 Workable draft of MultiTubeOD
    Basic app to interact with one or more MultiTubeOD devices.
    Configure Hardware is useful for when multiple devices are connected.
    Start New Run helps the user collect blanks and set a reference tube.
    Experiments run in independent infinite loops.
    Run info and instrument usage are each stored in pickles.
    The home page makes an accordion of active experiments where growth can be monitored and the run can be stopped.
2024-01-23 Delete Book1 (version 1).xlsx
    deleting defunct files
    [Book1 (version 1).xlsx]
2024-01-24 fix to no option for reference tube
    If no references available, input.universal_reference is never rendered. an IF statement referencing that value messes things up, leaving an empty list of choices.
2024-01-24 only free up reference if not being shared
    previously, every run set reference port usage to 0 when experiment stopped. This creates conflict with other running experiments that rely on that port. Added a condition to check if the port is bei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
    Also, minor modifications to make code clearer.
2024-01-25 added modal to tell user to connect a device
    Could be good to add a button to this modal that would automatically restart the app. Looking into python equivalent of session$reload()
2024-01-31 commenting out exceptions logged to data file
    and cleaning up some print statements
2024-03-11 Fix bugs in start/stop runs
    Add universal ref checkbox to reset button. If not reset, it can retain value of True while being hidden and supposedly impossible to use.
    Fix blanks from double counting the reference port. Previous behavior allowed stopping the original run to delete the port from usage even if running experiments still tried to use it.
2024-03-11 Allow app to run without device connected
    comment out the missing device stop app modal
2024-03-11 comment out ports_blanked troubleshooting
    print to output on sidebar to watch progression
2024-03-13 Add when things go wrong section
    Currently just text with ideas of things to watch for and ways the user can troubleshoot.
2024-03-13 Req selected ports before blanking
    Without this, user could click commit_blanks button and try to take reading of no ports, leading to problems.
    With this, button is dead until at least one tube is ready to run.
2024-03-13 Fix device configuration leading to constant readings
    fixed binary calculation for changing FIO EIO to analog (switched to firmware ports instead of user ports)
2024-04-03 Change DAC voltages
2024-04-10 Update Device.py
    added reminder about static methods.
2024-04-14 Update object-reorienting
    Stabilized a mechanism for updating/syncing the pickle, object inventories and physical devices.
2024-04-17 Begin making calibration functions
2024-04-17 Add voltage control to time course
2024-07-10 Offload work onto objects
    Created classes for
    -Experiments
    -Devices
    -Ports
    All are linked. Each class carries methods for handling the objects. Still don't have calibration figured out...
    Objects are used for the interface, to collect user input and to build a header for the output file. The lightweight "timecourse.py" function is called as a subprocess and interprets the header to begin an assay.
    No longer need the "sampling" module, since functions were either made irrelevant with or moved into appropriate class/static methods
2024-07-11 Update and rename Device.py to device.py
2024-07-11 Confirmed to work with classes and multiple devices. Analysis not working yet.
2024-07-11 Fix default reference device to match default test devices when multiple devices
2024-07-30 Remove Reference port and allow manual selection of device (in case they are indifferent temperatures users will need the choice)
2024-08-01 Add calibration mechanism
    [Calibration.tsv]
2024-08-01 Fix legend shows wrong numbers when calibration data not provided.
2024-08-01 Fix user experience, remove wait time, show waiting plot, align buttons, etc.
2024-08-01 Fix OD calibration import, cross section was looking for wrong index type
    [Calibration.tsv]
2024-08-30 Physical parts and electrical components
    [3181-00-01.SLDPRT, 3181-03-00.SLDASM, 3181-03-00.SLDDRW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]
2024-09-16 Create calibration.tsv table
    [Calibration.tsv]
2024-09-17 Rename LED data sheet.pdf to Parts/LED data sheet.pdf
2024-09-17 Rename Sensor data sheet.pdf to Parts/Sensor data sheet.pdf
